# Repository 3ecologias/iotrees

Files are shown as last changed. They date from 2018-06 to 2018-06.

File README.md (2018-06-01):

    This program is free software: you can redistribute it and/or modify
    it under the terms of the GNU General Public License as published by
    the Free Software Foundation, either version 3 of the License, or
    (at your option) any later version.

    This program is distributed in the hope that it will be useful,
    but WITHOUT ANY WARRANTY; without even the implied warranty of
    MERCHANTABILITY or FITNESS FOR A PARTICULAR PURPOSE.  See the
    GNU General Public License for more details.

    You should have received a copy of the GNU General Public License
    along with this program.  If not, see <http://www.gnu.org/licenses/>

Code by 3ecologias.net <root@3ecologias.net>

Precision dendrometer for measuring initial size and growth variations of tree diameter (DBH - diameter at breast height with bark).

  * 1 lap lapV = ~ 0.5 volts (v) vcc 5v
  * 1 lap lapC = ~ 7.9 cm
  * extra perimeter cE = ~ 4 cm
  * total perimeter cT = ~ 64 cm
  * initial diameter dI = ~ 1.2732 cm
  * final diameter dT = ~ 20.3718 cm
  * red led: pre-calibration
  * green led: mode of calculation of diameter (DAP) and growth (ICAd) in cm.
   
   steps:

  1. adjust the sensor spool and attach the device to the tree with the device turned off;
  2. Turn on the device to enable calibration mode, initial diameter measurement, growth and data cataloging;
  3. The sensor calibration mode checks whether the spool has completed a complete revolution;
  4. Measurement mode of the DAP and ICAd captures for 20 seconds the initial value of the diameter;
  5. The growth mode collects the diameter value (DAP) and compares it with the last value of the DAP to register the diameter increase (ICAd);
  6. The catalog mode stores, every minute, a CSV log on the SDCard with the DAP values: initial, final and ICAd.
  7. To save the log, simply return the spool to the starting position and wait for the red LED to light up. After that, turn off the device and remove the SDCard.

  info:
  the printed-circuit/ folder contains the PDF files for printed circuit board, the original file for editing by Fritizing (http://fritzing.org/), the protoboard assembly model, and the file with the list of required components.

  the string-pot-am-2674/ folder contains the modeled sensor files for 3D printing, sample photos, and bill of materials for the sensor.

  obs: 
  The potentiometer used appears in both listings, although only one potentiometer is used. The aim is for the two bills of material to be independent and modular.
  
  An Arduino Mega was used for the prototype

======== pt-BR ======

Dendrômetro de precisão para mensurar tamanho inicial e variações de crescimento do diâmetro das árvores (DAP - diâmetro a altura do peito com casca).

   * 1 lap lapV =~ 0.5 volts (v) vcc 5v
   * 1 lap lapC =~ 7.9 cm
   * perimetro extra cE =~ 4 cm
   * perimetro total cT =~ 64 cm
   * diametro inicial dI =~ 1.2732 cm
   * diametro final dT =~ 20.3718 cm
   * led vermelho: pre-calibragem 
   * led verde: modo de cálculo do diâmetro (DAP) e do crescimento (ICAd) em cm.
   
   steps:
   1. ajuste o carretel do sensor e acople o dispositivo na árvore com o dispositivo desligado;
   2. ligue o dispositivo para habilitar o modo de calibragem, medição inicial do diâmetro, crescimento e catalogo de dados;
   3. o modo de calibragem do sensor verifica se o carretel realizou no mímino uma volta completa;
   4. o modo de medição do DAP e ICAd captura por 20 segundos o valor inicial do diâmetro;
   5. o modo de crescimento coleta, a cada minuto, o valor do diâmetro (DAP) e compara com o último valor do DAP para registrar o incremento do diâmetro (ICAd);
   6. o modo de catalogo armazena, a cada minuto, um log em CSV no SDCard com os valores do DAP: inicial, final e o ICAd. 
   7. Para salvar o log, basta voltar o carretel para a posição inicial e aguardar o led vermelho acender. Depois disso, desligue o dispositivo e remova o SDCard.

   info:
   a pasta printed-circuit/ contém os arquivos PDF para impressão de circuito impresso, o arquivo original para edição pelo Fritizing (http://fritzing.org/), o modelo de montagem de protoboard e o arquivo com a lista de componentes necessários.

   a pasta string-pot-am-2674/ contém os arquivos modelados do sensor para a impressão 3D, fotos de exemplo e lista de materiais para o sensor.

   obs: 
   o potenciômetro utilizado aparece nas duas listagens, embora apenas um potênciometro seja utilizado. O objetivo é que as duas listas de materiais sejam independentes e modulares.

   Foi utilizado um Arduino Mega para o protótipo

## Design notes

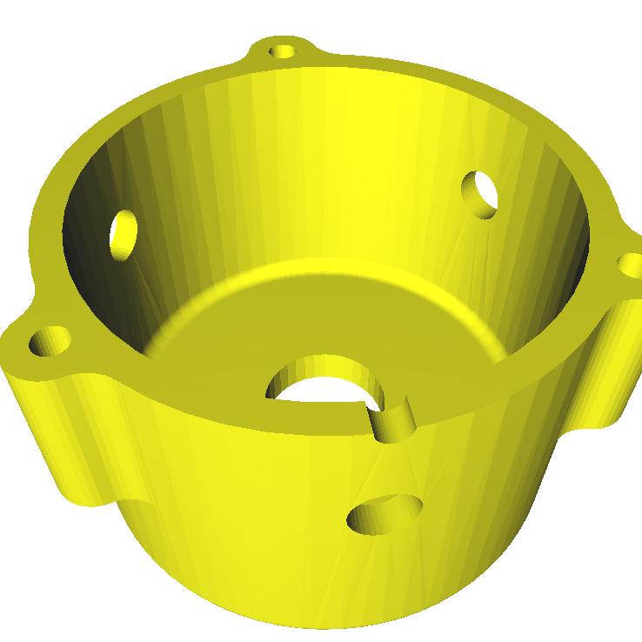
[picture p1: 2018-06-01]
string-pot-am-2674_v.0.4/string-pot-case.png

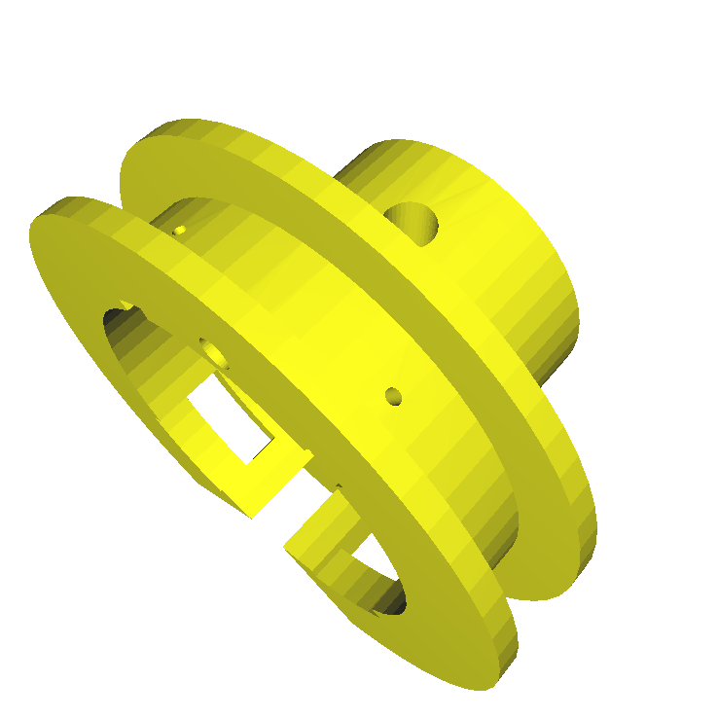
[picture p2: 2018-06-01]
string-pot-am-2674_v.0.4/string-pot-spool.png

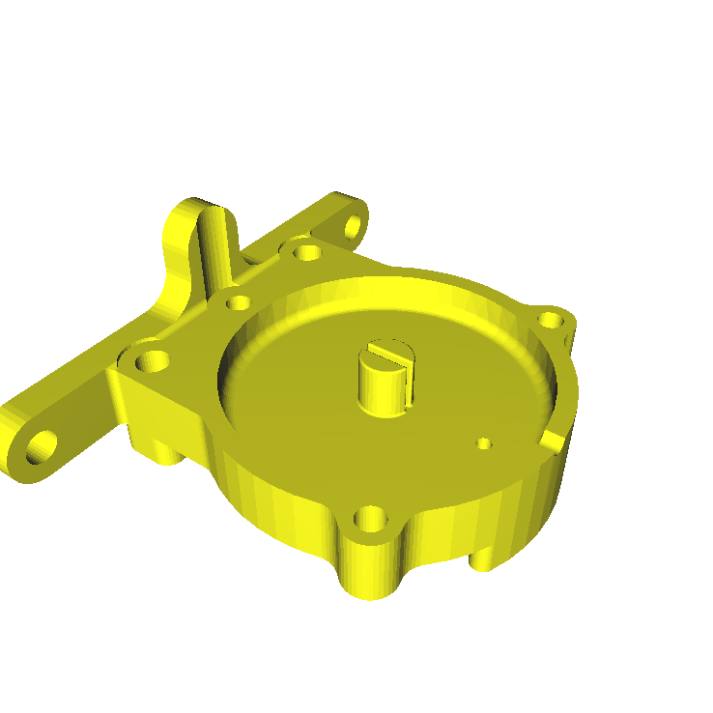
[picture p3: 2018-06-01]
string-pot-am-2674_v.0.4/string-pot-cap.png

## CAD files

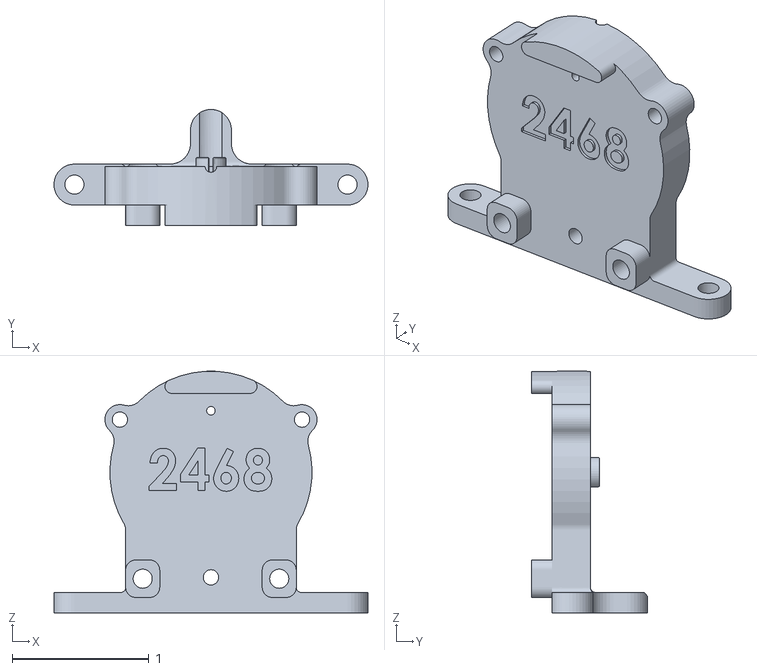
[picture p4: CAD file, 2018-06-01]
string-pot-am-2674_v.0.4/2468 String Pot - Cap.STL
2.30 x 0.85 x 1.77

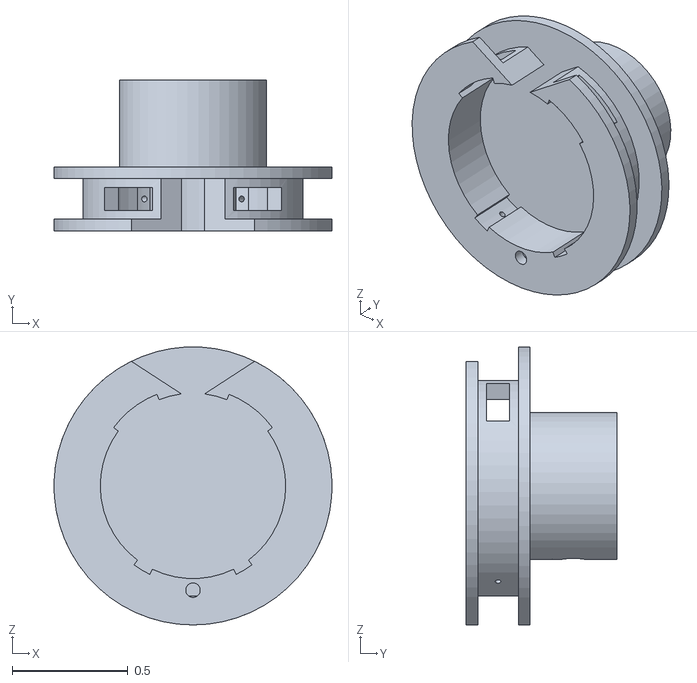
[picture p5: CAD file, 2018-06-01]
string-pot-am-2674_v.0.4/2468 String Pot - Spool.STL
1.20 x 0.65 x 1.20

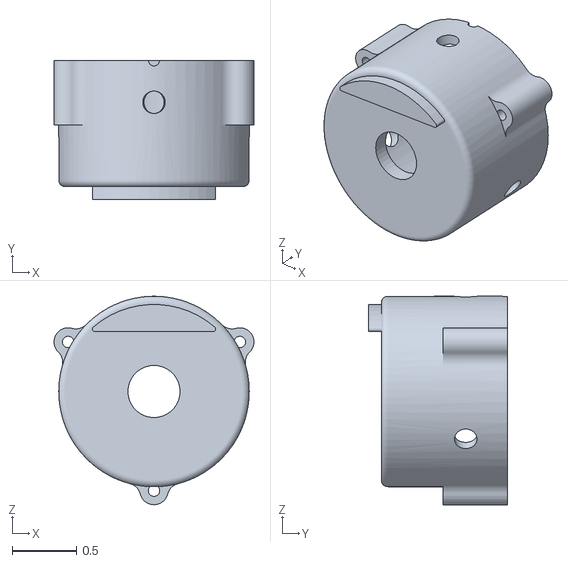
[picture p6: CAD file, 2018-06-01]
string-pot-am-2674_v.0.4/2468 String Pot - Case.STL
1.55 x 1.08 x 1.62

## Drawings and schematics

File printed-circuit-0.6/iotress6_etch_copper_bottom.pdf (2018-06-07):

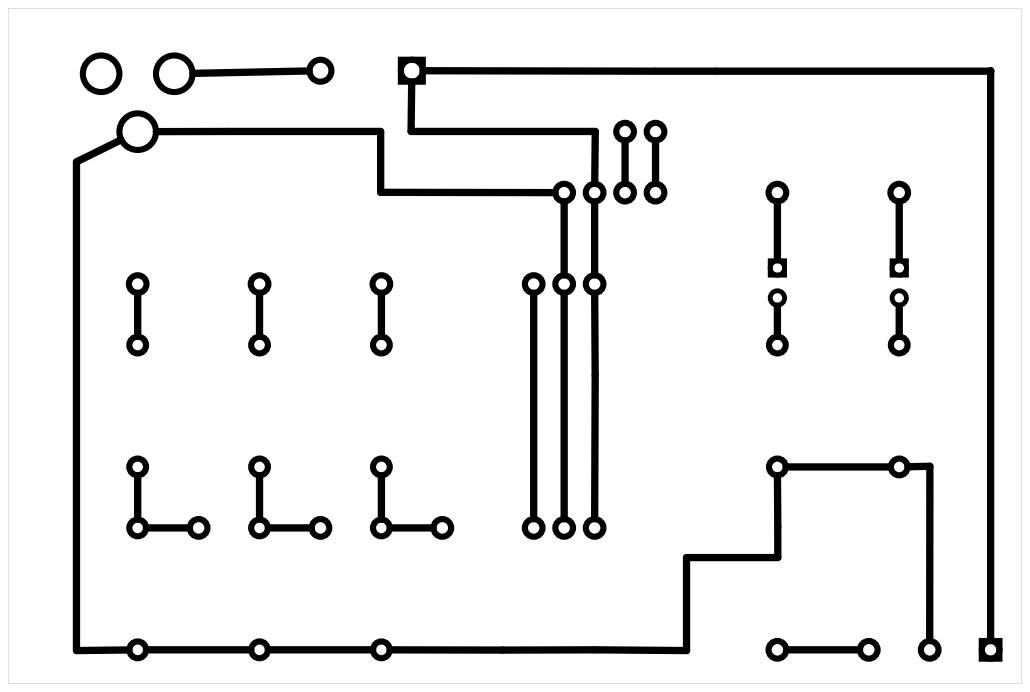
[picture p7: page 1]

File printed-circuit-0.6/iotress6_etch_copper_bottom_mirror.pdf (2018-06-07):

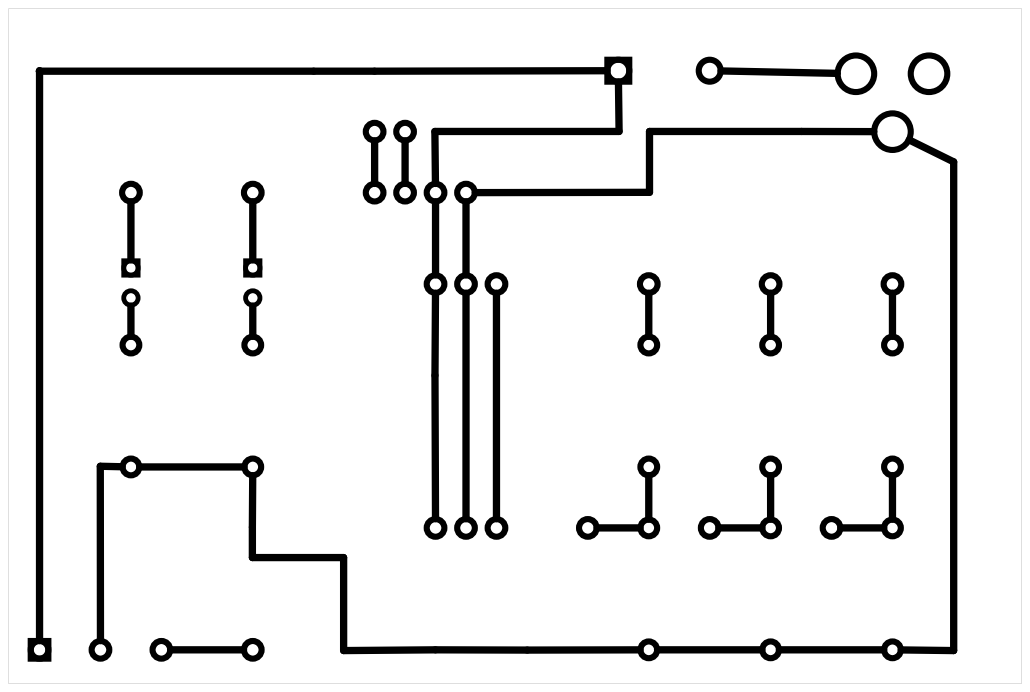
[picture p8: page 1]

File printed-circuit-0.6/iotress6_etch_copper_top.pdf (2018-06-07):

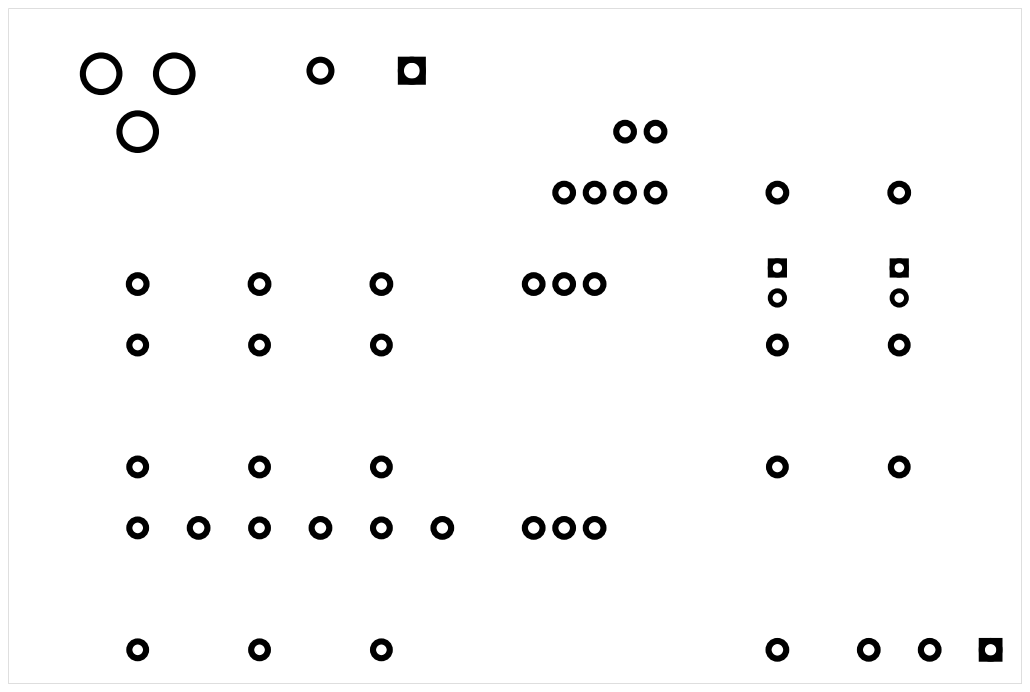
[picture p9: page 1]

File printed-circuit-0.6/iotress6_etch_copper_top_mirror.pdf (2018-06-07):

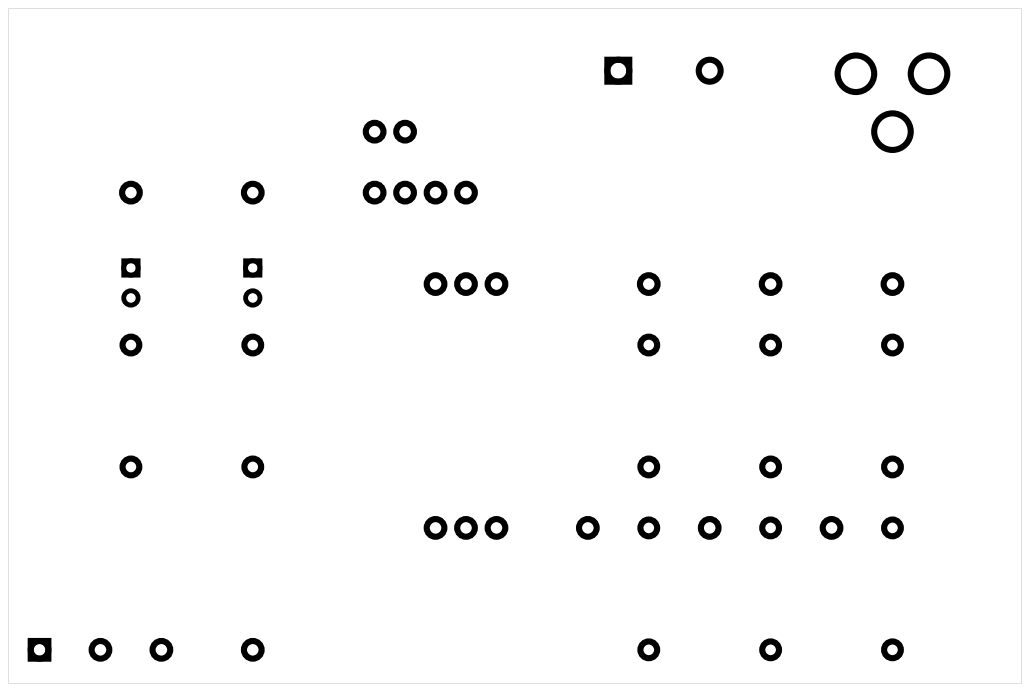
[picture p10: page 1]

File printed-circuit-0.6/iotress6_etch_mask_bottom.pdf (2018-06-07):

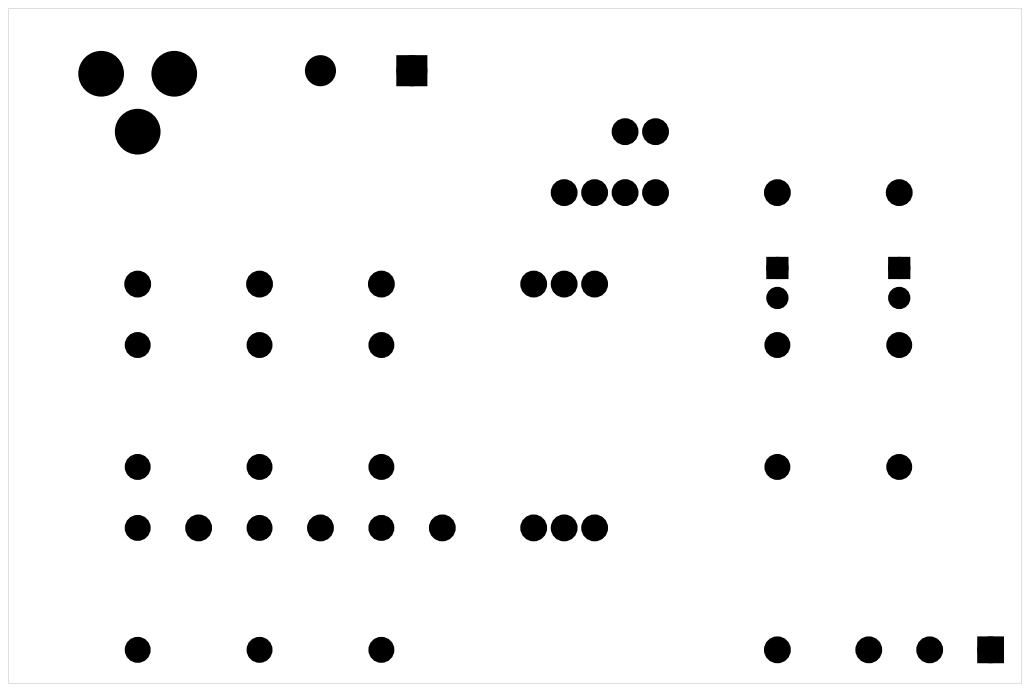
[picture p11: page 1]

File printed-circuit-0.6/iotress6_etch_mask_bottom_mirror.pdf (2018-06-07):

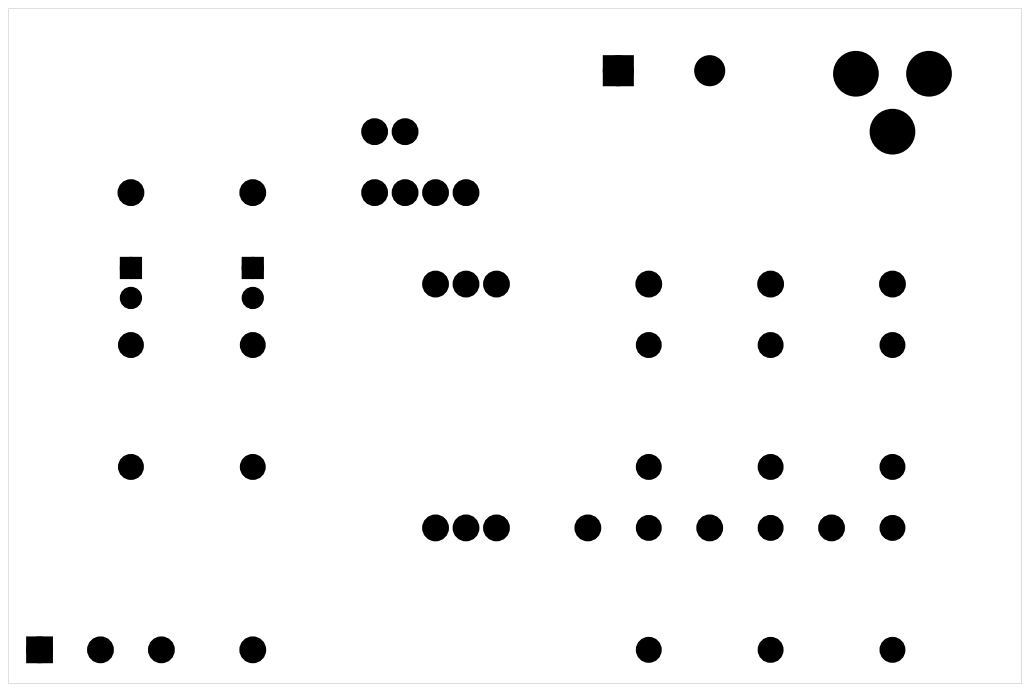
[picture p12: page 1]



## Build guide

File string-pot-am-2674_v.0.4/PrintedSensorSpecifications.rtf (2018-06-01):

Sensor Hardware:
• Three - 4-40 x 0.75" Screws (to seal the enclosure)
• One - 4-40 x 3/8" SHCS (to capture the potentiometer shaft)
• One - Retractable String component
• One - Precision Potentiometer, 10 turn, 5Koh
• One - String Potentiometer Enclosure
Specifications:
• Retractable String Length: ~27 inch
• Spool Circumference: 2.985 in (+/- 0.1)
Note: With the retractable string provided you will only be able to get about eight to nine turns out of the ten turn potentiometer. To get the full range, use the spring from the retractable string component and a 30" string instead.

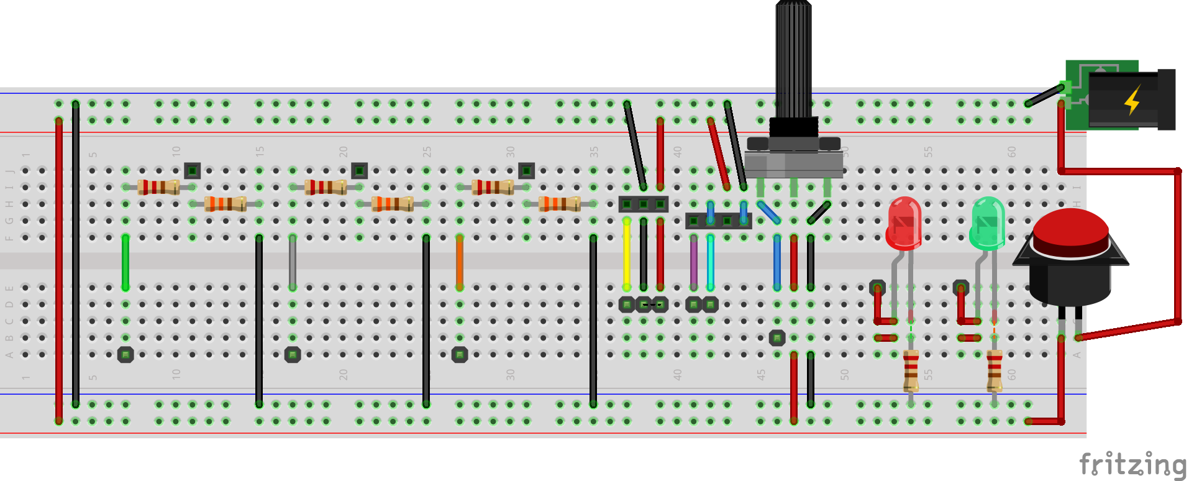
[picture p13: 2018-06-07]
printed-circuit-0.6/iotress6.1_bb.png

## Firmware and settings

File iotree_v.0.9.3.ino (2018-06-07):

/*  Dendrometro de precisão para mensurar tamanho inicial e 
 *   variações de crescimento do diâmetro das árvores 
 *   (DAP - diametro a altura do peito com casca). 
 *  
 *  Code by 3ecologias.net <root@3ecologias.net>
 *  
 *  notes:
 *  1 lap lapV =~ 0.5 volts (v) vcc 5v
 *  1 lap lapC =~ 7.9 cm
 *  perimetro extra cE =~ 4 cm
 *  perimetro total cT =~ 64 cm
 *  diametro inicial dI =~ 1.2732 cm
 *  diametro final dT =~ 20.3718 cm
 *  led vermelho: pre-calibragem 
 *  led verde: modo de cálculo do diâmetro (DAP) e do crescimento (ICAd) em cm.
 *  
 *  steps:
 *  1. ajuste o carretel do sensor e acople o dispositivo na árvore com o dispositivo desligado;
 *  2. ligue o dispositivo para habilitar o modo de calibragem, medição inicial do diâmetro, crescimento e catalogo de dados;
 *  3. o modo de calibragem do sensor verifica se o carretel realizou no mímino uma volta completa;
 *  4. o modo de medição do DAP e ICAd captura por 20 segundos o valor inicial do diâmetro;
 *  5. o modo de crescimento coleta, a cada minuto, o valor do diâmetro (DAP) e compara com o último valor do DAP para registrar o incremento do diâmetro (ICAd);
 *  6. o modo de catalogo armazena, a cada minuto, um log em CSV no SDCard com os valores de hora, data e o DAP: inicial, final e o ICAd. 
 *  7. Para salvar o log, basta voltar o carretel para a posição inicial e aguardar o led vermelho acender. Depois disso, desligue o dispositivo e remova o SDCard.
*/

// =*= RTC CLOCK DS1307 AND SDCARD CONFIG =*=

#include <Wire.h>
#include <TimeLib.h>
#include <DS1307RTC.h>

#include <SdFat.h>

// SPI pinout
#define PIN_SPI_CLK 13
#define PIN_SPI_MOSI 11
#define PIN_SPI_MISO 12
#define PIN_SD_CS 4

#define PIN_OTHER_DEVICE_CS -1

#define SD_CARD_SPEED SPI_FULL_SPEED 

#define FILENAME "datalogger.csv"

SdFat sd;
SdFile csv;

// =*= END SDCARD CONFIG =*=

// scope of constant
const int sensorPin = A0;    // pin that the dendro string pot sensor is attached to
const int ledPre = 6;
const int ledCap = 5;
const float Pi = 3.14159265359;

// scope of variables

// modules 
bool record = true;
bool calibrate = true;
bool measurement = false;
bool growth = false;
bool catalog = false;
bool calibrateState = true;
bool meansurementState = false;

// global variables
float sensorValue = 0;
float lapC = 780; // perimetro (cm) x 100
float lapV = 49; // volts (V) x 100
float cE = 200; // perimetro (cm) x 100
float baseline = 49; // perimetro externo inicial
int laps = 0;

float cI = 0; // perimetro inicial (cm)
float cL = 0; // perimetro final (cm)
float dI = 0; // diametro inicial (cm)
float dL = 0; // diametro final (cm)
float dapI = 0; // diametro inicial a altura do peito (cm)
float dapL = 0; // diametro final a altura do peito (cm)
float ICAd = 0.0000; // incremento de diametro (cm)
float voltage = 0;
String dataLogger ="";
tmElements_t tm;

void setup() {
  // Setup SdCard Pins
  pinMode(PIN_SPI_MOSI, OUTPUT);
  pinMode(PIN_SPI_MISO, INPUT);
  pinMode(PIN_SPI_CLK, OUTPUT);
  //Disable SPI devices
  pinMode(PIN_SD_CS, OUTPUT);
  digitalWrite(PIN_SD_CS, HIGH);
  
  #if PIN_OTHER_DEVICE_CS > 0
    pinMode(PIN_OTHER_DEVICE_CS, OUTPUT);
    digitalWrite(PIN_OTHER_DEVICE_CS, HIGH);
  #endif //PIN_OTHER_DEVICE_CS > 0
 
 Serial.begin(9600);
 // turn on LED to signal the start of the calibration and capture period:
 pinMode(ledPre, OUTPUT);
 pinMode(ledCap, OUTPUT);
 

 // Setup SD card boot
  if (!sd.begin(PIN_SD_CS, SD_CARD_SPEED)) {
    Serial.println("SD card begin error");
    return;
  }
}
// sdcard create csv file
void initSdFile()
{
  if (sd.exists(FILENAME) && !sd.remove(FILENAME))
  {
    Serial.println("Failed init remove file");
    return;
  }
  if (!csv.open(FILENAME, O_RDWR | O_CREAT)) {
    Serial.println("Failed open file");
  } else {
    Serial.println("Sdcard saving!");
  }
}

void loop() {

  Serial.println("===== IOTr3es =====");
  Serial.println("===== BUILDING MODULES =====");
  sensorValue = analogRead(sensorPin);
  voltage = (sensorValue * (5.0 / 1023.0)) * 100;
  
  // calibration mode
 while (calibrate == true) {
  Serial.println("===== CALIBRATE MODE =====");
  sensorValue = analogRead(sensorPin);
  voltage = (sensorValue * (5.0 / 1023.0)) * 100;
  digitalWrite(ledPre, HIGH); 
  // check pot minimum sensor value
   if (voltage >= baseline) {
    for (int i = 0; i < 10; i++) {
     voltage = (sensorValue * (5.0 / 1023.0)) * 100;
     cI = getcI(lapC, lapV, voltage);
     cI = cI + cE;
     dI = cI / Pi;
     Serial.println("===== CALIBRATE SENSOR =====");
     delay(100);
    }
    digitalWrite(ledPre, LOW);
    calibrate = false;
    measurement = true;
   }
   Serial.println("===== CALIBRATE WAITING =====");
   Serial.println("voltage" );
   Serial.println(rawData(voltage));
   delay(1000);
 }
 
  // meansurement mode
 while (measurement == true) {
  Serial.println("===== MEANSUREMENT MODE =====");
  digitalWrite(ledCap, HIGH);
  sensorValue = analogRead(sensorPin);
  voltage = (sensorValue * (5.0 / 1023.0)) * 100;
  // check pot minimum sensor value
   if (voltage >= baseline) {
    for (int i = 0; i < 20; i++) {
     sensorValue = analogRead(sensorPin);
     voltage = (sensorValue * (5.0 / 1023.0)) * 100;
     cI = getcI(lapC, lapV, voltage);
     cI = cI + cE;
     dapI = cI / Pi;
     delay(100);
    }
    measurement = false;
    growth = true;
   } else {
    measurement = false;
    calibrate = true;
   }
 }

// growth mode
 while (growth == true) {
  digitalWrite(ledCap, HIGH);
  for (int i = 0; i >= 60; i++) {
     digitalWrite(ledCap, LOW);
     delay(100);
     sensorValue = analogRead(sensorPin);
     voltage = (sensorValue * (5.0 / 1023.0)) * 100;
     digitalWrite(ledCap, HIGH);
     Serial.println("===== GROWTH TIME =====");
  }
  if (record == true) {
    Serial.println("===== INIT SDCARD MODULE =====");
    initSdFile();
    csv.println("HOUR, MINUTE, SECOND, DAY, MONTH, YEAR, DAP-I, DAP-L, ICAD");
    record = false;
  }
  // get dap last
  sensorValue = analogRead(sensorPin);
  voltage = (sensorValue * (5.0 / 1023.0)) * 100;
  // get last DAP value in cm
  cI = getcI(lapC, lapV, voltage);
  cL = cI + cE;
  dapL = cL / Pi;
  if (dapL > dapI) {
    ICAd = dapL - dapI;
     if (RTC.read(tm)) {    
        dataLogger = String(tm.Hour) + "," + String(tm.Minute) + "," + String(tm.Second) + "," + String(tm.Day) + "," + String(tm.Month) + "," + String(tmYearToCalendar(tm.Year)) + "," + String(rawData(dapI)) + "," + String(rawData(dapL)) + "," + String(rawData(ICAd));
        csv.println(dataLogger);
        Serial.println("Datalogger ok");
     }
  } else {
    ICAd = dapI - dapL;   
     if (RTC.read(tm)) {    
        dataLogger = String(tm.Hour) + "," + String(tm.Minute) + "," + String(tm.Second) + "," + String(tm.Day) + "," + String(tm.Month) + "," + String(tmYearToCalendar(tm.Year)) + "," + String(rawData(dapI)) + "," + String(rawData(dapL)) + "," + String(rawData(ICAd));
        csv.println(dataLogger);
        Serial.println("Datalogger ok");
     }
  }
  delay(10000);
  if (voltage <= baseline) {
     digitalWrite(ledCap, LOW);
     csv.close();
     Serial.println("SDCard saved!" );
     record = true;
     growth = false;
     calibrate = true;
  }
 }
}

// Function to get length
float getcI(float lapC, float lapV, float voltage){
  float _cIraw;
  float cIraw;
  _cIraw = lapC * voltage;
  cIraw = _cIraw / lapV;
  return cIraw;
}

// Function to convert data to cm
float rawData(float value){
  float rawD;
  rawD = value / 100;
  return rawD;
}

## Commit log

2018-05-09 Documentação e Licença
    Adicionada restante da documentação e demais arquivos. Adicionado GNU
    General Public License
    [2468 String Pot - Cap.STL, 2468 String Pot - Case.STL, 2468 String Pot - Spool.STL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]
2018-05-14 new fritizing with clock
    [iotress5_fritzing_file.fzz, iotress6.fzz]
